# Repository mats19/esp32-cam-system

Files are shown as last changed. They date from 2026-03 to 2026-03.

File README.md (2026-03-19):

# ESP32-Cam Autonomous MQTT Camera

## Concept
This circuit realizes an autonomous, battery-powered surveillance camera based on the ESP32-Cam (AI-Thinker model).

### Functionality
* **Autonomous Operation:** Designed for long-term battery use.
* **Interval Capture:** The ESP32 wakes up at defined intervals, captures a photo, and sends it via WiFi/MQTT to a Home Assistant instance.
* **Power Efficiency:** Uses Deep Sleep mode between cycles to minimize power consumption.
* **Manual Trigger:** A tactile button allows manual image triggering at any time.
* **Status Indication:** Two LEDs provide visual feedback for status or errors (e.g., connection issues).

## Project Structure
The repository is organized to separate hardware design from firmware development while maintaining a unified workspace.

```text
esp32-cam-system/           # Root directory (Open this in VS Code)
├── .gitignore              # Global ignore rules for PIO and KiCad
├── platformio.ini          # Central configuration (redirects to firmware/)
├── README.md               # Project documentation
├── .vscode/                # VS Code specific settings
│   ├── settings.json       # IntelliSense and include paths
│   └── tasks.json          # Build and Upload shortcuts
├── firmware/               # Firmware source files
│   └── src/                # .cpp and .h files (Logic & Headers)
├── hardware/               # KiCad PCB project
│   ├── esp32-cam-hw.kicad_pro
│   └── libraries/          # Local Footprints and Symbols
└── docs/                   # Datasheets, 3D models (STL), and images
```

## Development Environment & Settings

### PlatformIO & VS Code
To maintain a clean root directory while keeping firmware in a subfolder, the central `platformio.ini` is configured as follows:
* **Custom Paths:** Redirects `src_dir` and `include_dir` to the `firmware/` folder.
* **Hardware Abstraction:** PSRAM is explicitly enabled via build flags (`-DBOARD_HAS_PSRAM`) to handle image processing.
* **IntelliSense:** The `.vscode/settings.json` includes `${workspaceFolder}/firmware/src` to ensure header files are recognized without errors.

### KiCad Workflow
* **Portability:** All custom footprints and symbols are stored in `hardware/libraries/`.
* **Path Variables:** Library paths should use the `${KIPRJMOD}/libraries/` variable to ensure the project remains functional when cloned to different machines.

## Hardware Description

### Components

#### Main Board
* **U1 (ESP32-Cam AI-Thinker):** Core module containing the ESP32-S SoC, camera, and SD card slot.
* **J1 (Power Supply):** 2-pin JST-XH connector for 5V external power.
* **J2 (Programming):** 5-pin header for FTDI flashing and UART debugging.
* **J3 (Front Panel Link):** 4-pin socket to connect the daughterboard.

#### Daughterboard (Front Panel)
* **SW1 (Button):** Manual capture trigger, push button DTR 7/RT (Connects IO12 to GND).
* **D1 (Red LED):** Error indicator (MQTT/WiFi failure).
* **D2 (Status LED):** Activity indicator (Capturing/Processing).

### Connections and Pinout

| Pin | J2 (Programming) | J3 / J4 (Link) | GPIO | Description |
|---|---|---|---|---|
| 1 | 5V | GND | - | Common Ground |
| 2 | GND | TRIGGER | IO12 | Manual trigger / Wake-up |
| 3 | U0T (TX) | ERR_LED | IO13 | Error LED (Red) |
| 4 | U0R (RX) | STS_LED | IO15 | Status LED |
| 5 | IO0 | - | IO0 | Pull to GND for flashing |

## PCB Milling Specifications (Isolation Milling)
Optimized for CNC isolation milling on copper-clad boards.

### Manufacturing Parameters
* **Track Width:** 0.5 mm to 0.8 mm (Signals); 1.0 mm (Power).
* **Clearance (Isolation Gap):** 0.4 mm to 0.6 mm.
* **THT Pads:** Standard 2.0 mm outer diameter (1.0 mm drill). Custom footprints (e.g. SW1 DTR 7/RT) use 2.6 mm pads with 2.0 mm drills to maintain isolation gaps.
* **Thermal Reliefs:** Required for all pads in copper zones.
* **Antenna Cutout:** Instead of a standard keepout zone, a rectangle is drawn on the `User.Drawings` layer. This area under the ESP32-S PCB antenna will be completely milled out (freigefräst) to avoid WiFi signal attenuation.

### Milling Constraints
* **Tooling:** 30° Engraving Bit.
* **Depth of Cut:** 0.05 mm to 0.1 mm (Auto-leveling highly recommended).

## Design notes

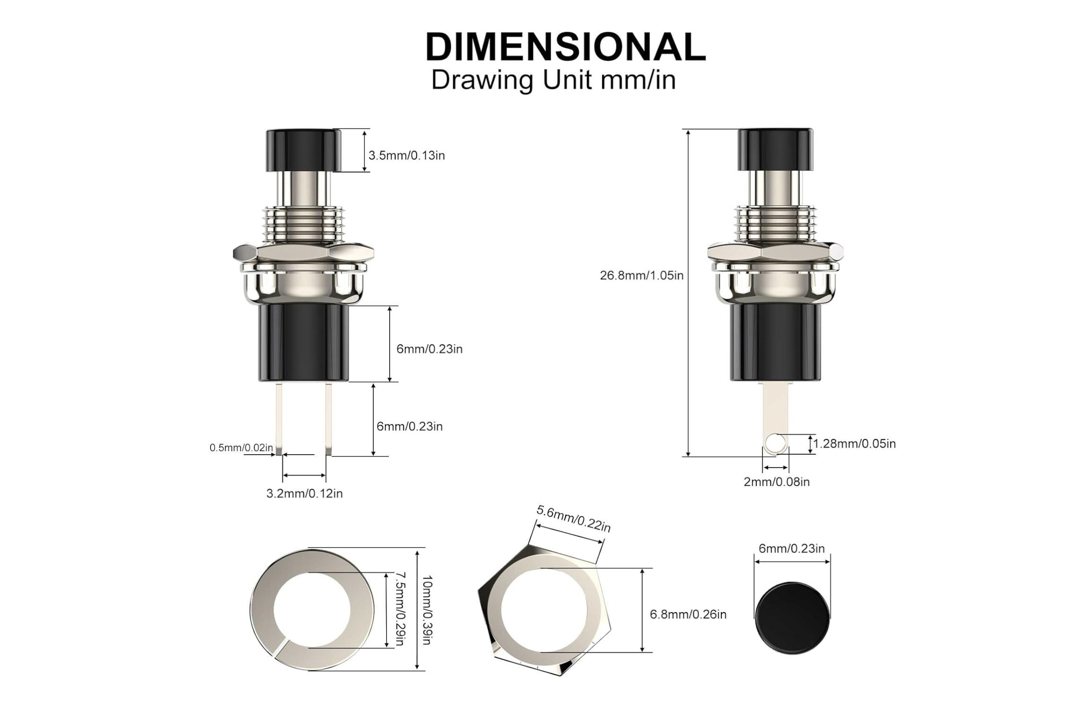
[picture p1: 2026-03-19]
docs/Taster DTR 7:rt.png

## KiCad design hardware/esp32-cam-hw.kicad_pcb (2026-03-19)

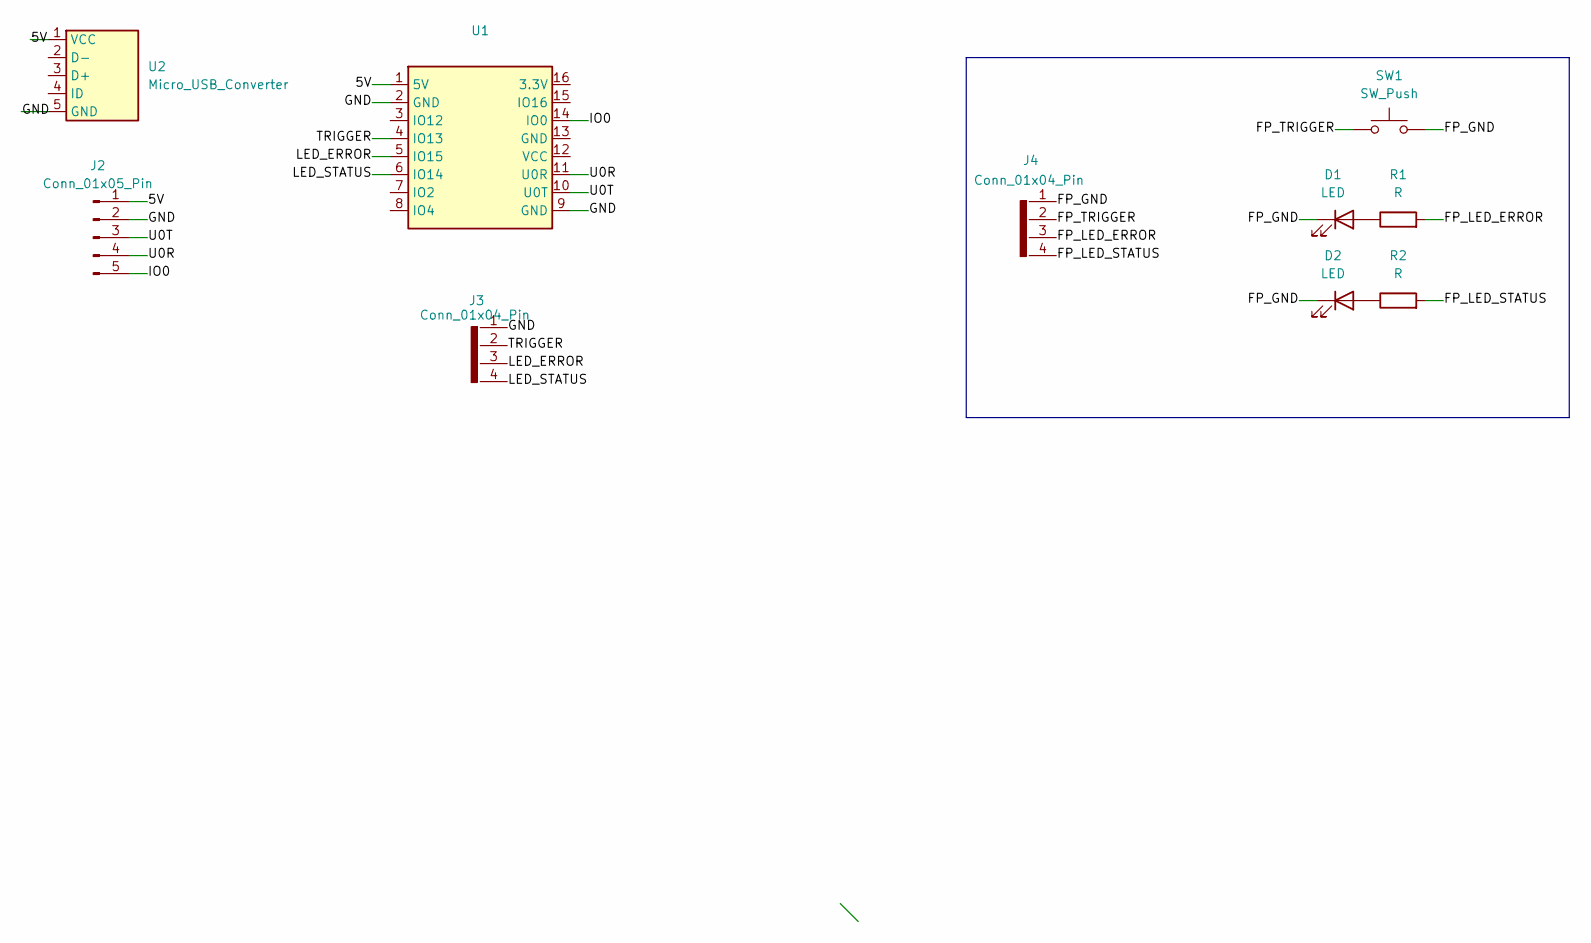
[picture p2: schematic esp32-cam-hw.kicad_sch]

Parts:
D1, D2: LED; LED_D5.0mm
J2: Conn_01x05_Pin; JST_EH_S5B-EH_1x05_P2.50mm_Horizontal
J3, J4: Conn_01x04_Pin; PinHeader_1x04_P2.54mm_Vertical
R1, R2: R; R_Axial_DIN0207_L6.3mm_D2.5mm_P7.62mm_Horizontal
SW1: SW_Push; SW_DTR_7_RT
U1: ESP32-Cam AI-Thinker Model
U2: Micro_USB_Converter

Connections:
/5V: J2.1, U1.1 (5V), U2.1 (VCC)
/FP_GND: D1.1 (K), D2.1 (K), J4.1, SW1.2
/FP_LED_ERROR: J4.3, R1.2
/FP_LED_STATUS: J4.4, R2.2
/FP_TRIGGER: J4.2, SW1.1
/GND: J2.2, J3.1, U1.2 (GND), U1.9 (GND), U2.5 (GND)
/IO0: J2.5, U1.14 (IO0)
/LED_ERROR: J3.3, U1.5 (IO15)
/LED_STATUS: J3.4, U1.6 (IO14)
/TRIGGER: J3.2, U1.4 (IO13)
/U0R: J2.4, U1.11 (U0R)
/U0T: J2.3, U1.10 (U0T)
unnamed: D1.2 (A), R1.1
unnamed: D2.2 (A), R2.1

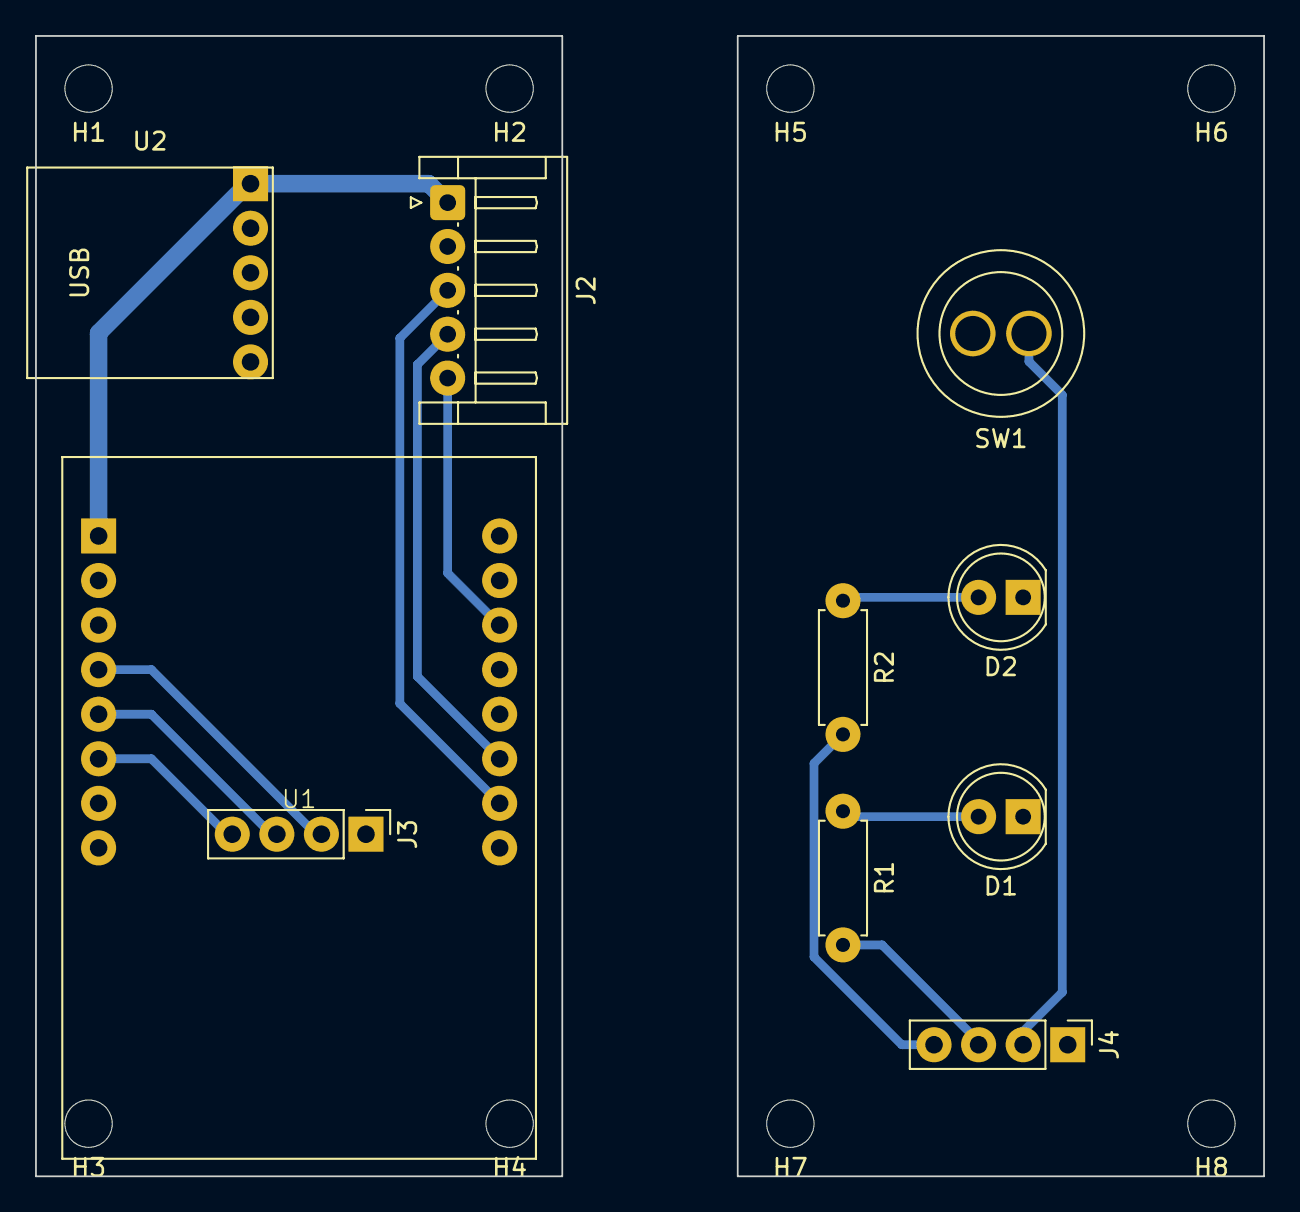
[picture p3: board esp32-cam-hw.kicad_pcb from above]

Board: 2 copper layers, 70.0 x 65.0 mm, 18 parts (0 on the bottom side), 14 nets.

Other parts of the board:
H1, H2, H3, H4, H5, H6, H7, H8: MountingHole_2.7mm_M2.5

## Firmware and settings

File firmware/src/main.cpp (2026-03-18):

#include <Arduino.h>
#include <WiFi.h>
#include <cstddef>
#include "config_manager.h"
#include "web_portal.h"
#include "camera_manager.h"
#include "mqtt_client.h"
#include "hardware_utils.h"

AppConfig config;

void takeAndSendPicture(bool& imageOk, bool& commOk) {
    imageOk = commOk = false;
    
    // Bei Foto-Aktion: Grüne LED an
    HardwareUtils::setSuccessLED(true);
    Serial.println("[PIC] Starting picture sequence...");

    // (re-)init camera
    if (!CameraManager::begin(config)) {
        Serial.println("Camera init failed.");
        HardwareUtils::setSuccessLED(false);
        HardwareUtils::setErrorLED(true);
        commOk = imageOk = false;
        return;
    }

    // Fire flash, give it a moment
    CameraManager::setFlash(true);
    delay(200);

    // Capture into CameraManager’s static buffer
    if (!CameraManager::captureFrame()) {
        Serial.println("Image capture failed.");
        CameraManager::setFlash(false);
        HardwareUtils::setSuccessLED(false);
        HardwareUtils::setErrorLED(true);
        commOk = imageOk = false;
        return;
    }
    CameraManager::setFlash(false);
    imageOk = true;
    Serial.println("[PIC] Capture successful.");

    // Grab pointer+length
    size_t len;
    const uint8_t* data = CameraManager::imageData(len);
    Serial.printf("[PIC] Image size: %zu bytes\n", len);

    // Publish raw buffer directly
    Serial.println("[PIC] Publishing to MQTT...");
    commOk = MQTTClient::publishImage(data, len);
    if (commOk) {
        Serial.println("Image sent!");
        // Erfolg: Grün aus (Ruhezustand)
        HardwareUtils::setSuccessLED(false);
        HardwareUtils::setErrorLED(false);
    } else {
        HardwareUtils::setSuccessLED(false);
        HardwareUtils::setErrorLED(true);
        Serial.println("Image send failed.");
        // Kein Halt mehr, damit Retry möglich ist (DeepSleep oder manueller Trigger)
    }
}

void setup() {
    Serial.begin(115200);
    // Wait a moment for serial monitor to connect
    delay(1000);
    Serial.println("\n\n--- ESP32-CAM Booting ---");

    ConfigManager::begin();
    HardwareUtils::setupButtonsAndLEDs();
    
    // Boot-Prozess Start: Rote LED an
    HardwareUtils::setErrorLED(true);
    Serial.println("[BOOT] Loading configuration...");

    bool configNeeded = !ConfigManager::load(config) || HardwareUtils::isConfigButtonPressed();
    if (configNeeded) {
        Serial.println("[BOOT] No valid config or button pressed. Starting Web Portal.");
        WebPortal::begin(config, [](){ ESP.restart(); });
    } else {
        Serial.printf("[BOOT] Config loaded. Connecting to WiFi SSID: %s\n", config.wifi_ssid.c_str());
        WiFi.begin(config.wifi_ssid.c_str(), config.wifi_password.c_str());
        unsigned long start = millis();
        while (WiFi.status() != WL_CONNECTED && millis() - start < 15000) {
            delay(500);
            Serial.print(".");
        }
        Serial.println();

        if (WiFi.status() != WL_CONNECTED) {
            Serial.println("[FATAL] WiFi connection failed! Going to sleep and retry later.");
            HardwareUtils::setErrorLED(true);
            delay(2000);
            // Nicht Config löschen! Sonst bleibt das Gerät hängen.
            // Versuche es in 60 Sekunden erneut.
            esp_sleep_enable_timer_wakeup(60ULL * 1000000ULL);
            esp_deep_sleep_start();
        }

        Serial.printf("[BOOT] WiFi connected. IP: %s\n", WiFi.localIP().toString().c_str());
        Serial.println("[BOOT] Connecting to MQTT...");
        MQTTClient::begin(config);
        unsigned long t0 = millis();
        while (!MQTTClient::isConnected() && millis() - t0 < 5000) { MQTTClient::loop(); delay(50);} 
        
        if (MQTTClient::isConnected()) { 
            Serial.println("[BOOT] MQTT connected. Publishing discovery and availability.");
            MQTTClient::publishDiscovery(config); 
            MQTTClient::publishAvailability(true);
            // Abschluss Verbindung: Grün dazu, warten, dann beide aus
            HardwareUtils::setSuccessLED(true);
            delay(1000);
            HardwareUtils::setSuccessLED(false);
            HardwareUtils::setErrorLED(false);
        } else {
            Serial.println("[ERROR] MQTT connection failed.");
            // Rote LED bleibt an, aber wir machen weiter
        }

        Serial.println("[BOOT] Taking initial picture...");
        bool imageOk = false, commOk = false;
        takeAndSendPicture(imageOk, commOk);

        Serial.println("[MAIN] Entering 15s window for manual trigger or config mode...");

        // TEST-MODUS: Zeige aktuellen Status an
        Serial.printf("[TEST] Initial Button State (IO12): %s\n", HardwareUtils::isManualTriggerPressed() ? "PRESSED (LOW)" : "RELEASED (HIGH)");
        
        unsigned long windowStart = millis();
        while (millis() - windowStart < 15000) {
            if (HardwareUtils::isManualTriggerPressed()) {
                Serial.println("[TEST] Button signal detected (PRESSED)!");
                unsigned long pressStart = millis();
                
                // Warten auf Loslassen mit Timeout (Schutz gegen Hängenbleiben)
                while (HardwareUtils::isManualTriggerPressed()) {
                    delay(10);
                    // Timeout nach 3 Sekunden, falls der Button klemmt
                    if (millis() - pressStart > 3000) {
                        Serial.println("[TEST] TIMEOUT: Button seems stuck LOW. Breaking loop to continue.");
                        break; 
                    }
                }

                unsigned long pressMs = millis() - pressStart;
                Serial.printf("[TEST] Button RELEASED after %lu ms\n", pressMs);

                if (pressMs >= 1500) {
                    Serial.println("[ACTION] Long press detected. Entering config mode.");
                    WebPortal::begin(config, [](){ ESP.restart(); });
                    break;
                } else {
                    Serial.println("[ACTION] Short press detected. Taking picture.");
                    takeAndSendPicture(imageOk, commOk);
                    // Reset window timer after taking a picture
                    windowStart = millis();
                }
            }
            // WICHTIG: MQTT-Verbindung am Leben erhalten (KeepAlive senden),
            // sonst trennt der Broker die Verbindung wegen Timeout (k15)
            MQTTClient::loop();
            delay(10);
        }
        
        // After 15s window, decide whether to sleep or stay in web portal mode
        if (WebPortal::isActive()) {
            Serial.println("[MAIN] Web portal is active. Staying awake.");
            // Turn off status LEDs, we are in portal mode now
            HardwareUtils::setErrorLED(false);
            HardwareUtils::setSuccessLED(false);
        } else {
            Serial.println("[MAIN] 15s window timed out. Going to sleep for 1 minute.");
            if (MQTTClient::isConnected()) {
                MQTTClient::publishAvailability(false);
                delay(100); // Give MQTT time to send
            }
            
            // 1. Timer Wakeup (60 Sekunden)
            esp_sleep_enable_timer_wakeup(60ULL * 1000000ULL);

            // 2. Button Wakeup (Wenn IO12 auf GND gezogen wird)
            esp_sleep_enable_ext0_wakeup(GPIO_NUM_12, 0);
            // 2. Button Wakeup (Wenn IO14 auf GND gezogen wird)
            esp_sleep_enable_ext0_wakeup(GPIO_NUM_14, 0);

            Serial.println("[MAIN] Going to sleep (Wakeup: Timer or Button)...");
            Serial.flush(); // Warten bis Text gesendet wurde
            esp_deep_sleep_start();
        }
    }
}

void loop() {
    if (WebPortal::isActive()) {
        WebPortal::loop();
    }
    // In normal mode, MQTTClient::loop() is only called during connection attempts.
    // If we stay awake for other reasons, we might need to call it here.
    MQTTClient::loop();
}

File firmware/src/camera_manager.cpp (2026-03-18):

#include "camera_manager.h"
#include "config_manager.h"
#include <esp_camera.h>
#include <vector>
#include <Arduino.h>

#ifndef PWDN_GPIO_NUM
#define PWDN_GPIO_NUM     32
#define RESET_GPIO_NUM    -1
#define XCLK_GPIO_NUM      0
#define SIOD_GPIO_NUM     26
#define SIOC_GPIO_NUM     27
#define Y9_GPIO_NUM       35
#define Y8_GPIO_NUM       34
#define Y7_GPIO_NUM       39
#define Y6_GPIO_NUM       36
#define Y5_GPIO_NUM       21
#define Y4_GPIO_NUM       19
#define Y3_GPIO_NUM       18
#define Y2_GPIO_NUM        5
#define VSYNC_GPIO_NUM    25
#define HREF_GPIO_NUM     23
#define PCLK_GPIO_NUM     22
#endif

namespace CameraManager {

static std::vector<uint8_t> _imgBuf;
static bool _initialized = false;

bool begin(const AppConfig& config) {
    if (_initialized) return true; // Bereits initialisiert
    camera_config_t camCfg;
    camCfg.ledc_channel = LEDC_CHANNEL_0;
    camCfg.ledc_timer   = LEDC_TIMER_0;
    camCfg.pin_d0       = Y2_GPIO_NUM;
    camCfg.pin_d1       = Y3_GPIO_NUM;
    camCfg.pin_d2       = Y4_GPIO_NUM;
    camCfg.pin_d3       = Y5_GPIO_NUM;
    camCfg.pin_d4       = Y6_GPIO_NUM;
    camCfg.pin_d5       = Y7_GPIO_NUM;
    camCfg.pin_d6       = Y8_GPIO_NUM;
    camCfg.pin_d7       = Y9_GPIO_NUM;
    camCfg.pin_xclk     = XCLK_GPIO_NUM;
    camCfg.pin_pclk     = PCLK_GPIO_NUM;
    camCfg.pin_vsync    = VSYNC_GPIO_NUM;
    camCfg.pin_href     = HREF_GPIO_NUM;
    camCfg.pin_sccb_sda = SIOD_GPIO_NUM;
    camCfg.pin_sccb_scl = SIOC_GPIO_NUM;
    camCfg.pin_pwdn     = PWDN_GPIO_NUM;
    camCfg.pin_reset    = RESET_GPIO_NUM;

    camCfg.xclk_freq_hz = 20000000;
    camCfg.pixel_format = PIXFORMAT_JPEG;
    camCfg.frame_size   = (framesize_t)config.camera_resolution;
    camCfg.jpeg_quality = config.camera_quality > 0 ? config.camera_quality : 12;
    camCfg.fb_count     = 1;

    esp_err_t err = esp_camera_init(&camCfg);
    if (err != ESP_OK) {
        Serial.printf("Camera init failed 0x%x\n", err);
        return false;
    }
    _initialized = true;
    sensor_t* s = esp_camera_sensor_get();
    if (s) {
        s->set_brightness(s, config.camera_brightness);
        s->set_contrast(s,   config.camera_contrast);
        s->set_saturation(s, config.camera_saturation);
        s->set_whitebal(s,   config.camera_wb_mode);
        s->set_hmirror(s,    config.camera_hflip);
        s->set_vflip(s,      config.camera_vflip);
    }
    return true;
}

bool captureFrame() {
    camera_fb_t* fb = esp_camera_fb_get();
    if (!fb || fb->format != PIXFORMAT_JPEG) {
        if (fb) esp_camera_fb_return(fb);
        return false;
    }
    _imgBuf.assign(fb->buf, fb->buf + fb->len);
    esp_camera_fb_return(fb);
    return true;
}

const uint8_t* imageData(std::size_t& len) {
    len = _imgBuf.size();
    return _imgBuf.data();
}

void setFlash(bool on) { pinMode(4, OUTPUT); digitalWrite(4, on ? HIGH : LOW); }
void setBrightness(int b) { if (auto s = esp_camera_sensor_get()) s->set_brightness(s, b); }
void setContrast(int c)   { if (auto s = esp_camera_sensor_get()) s->set_contrast(s, c); }
void setSaturation(int s) { if (auto sensor = esp_camera_sensor_get()) sensor->set_saturation(sensor, s); }
void setWBMode(int m)     { if (auto s = esp_camera_sensor_get()) s->set_whitebal(s, m); }
void setQuality(int q)    { if (auto s = esp_camera_sensor_get()) s->set_quality(s, q); }
void setFrameSize(framesize_t fs) { if (auto s = esp_camera_sensor_get()) s->set_framesize(s, fs); }
void setFlip(bool h, bool v) { if (auto s = esp_camera_sensor_get()) { s->set_hmirror(s, h); s->set_vflip(s, v); } }

} // namespace CameraManager

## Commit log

2026-03-18 Migration inkl. Libraries abgeschlossen
    [esp32-cam-hw.kicad_pcb, esp32-cam-hw.kicad_sch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]
2026-03-18 Initial migration: restructured ESP32-CAM project
2026-03-18 Fix: converted firmware submodule to regular folder
    [camera_manager.cpp, hardware_utils.cpp]
2026-03-18 Restructured project: Unified PlatformIO and KiCad root, optimized .gitignore, and configured VS Code tasks
2026-03-18 docs: Translate README to English and expand project documentation
    - Translated the core concept and hardware descriptions from German to English.
    - Added a detailed project directory structure tree.
    - Formatted hardware components and connections into clear lists and tables.
    - Included PlatformIO and KiCad development environment settings.
    - Added CNC isolation milling specifications and constraints for the PCB.
2026-03-19 Hardware: Center front panel components and add custom switch footprint
    - Centered front panel components (SW1, D1, D2, J3, J4) precisely on the X-axis for optical symmetry.
    - Added a custom KiCad footprint for the DTR 7/RT push button (9.5mm body, round).
    - Adjusted THT pad sizes for the custom switch (2.6mm outer diameter, 2.0mm drill) to guarantee a minimum 0.6mm gap for CNC isolation milling.
    - Updated README.md to reflect the specific switch model and adjusted PCB milling specifications.
    [esp32-cam-hw.kicad_pcb, esp32-cam-hw.kicad_sch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]
2026-03-19 Hardware: Replace antenna keepout zone with milling rectangle
    - Removed the standard KiCad keepout zone under the ESP32-S antenna.
    - Added a filled rectangle on the `Dwgs.User` (User.Drawings) layer to serve as a precise milling pocket for CNC isolation routing.
    - Adjusted the GND copper polygon to perfectly avoid the antenna region.
    - Updated README.md to document the new antenna cutout milling procedure.
    [esp32-cam-hw.kicad_pcb]
